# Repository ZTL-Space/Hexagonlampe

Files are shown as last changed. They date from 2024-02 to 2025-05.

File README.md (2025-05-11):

# Hexagonlampe

Die Hexagonlampe wird aus CNC-Gefrästen Holz- und Plexiglasteilen zusammengebaut.

Die Idee stammt von [hier](https://hackaday.com/2019/02/21/hexagonal-lamp-is-a-stylish-application-of-plywood/).

Im Gegensatz zum Original werden hier LED-Stripes montiert, die von einem ESP32 angesteuert werden.

Die Steuerung erfolgt über einen Taster, der betätigt wird, wenn man oben auf die Lampe drückt bzw. über WLAN und MQTT.

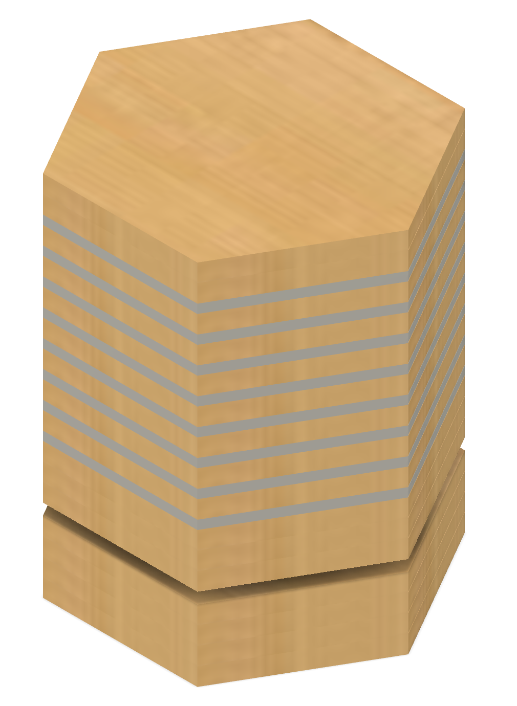
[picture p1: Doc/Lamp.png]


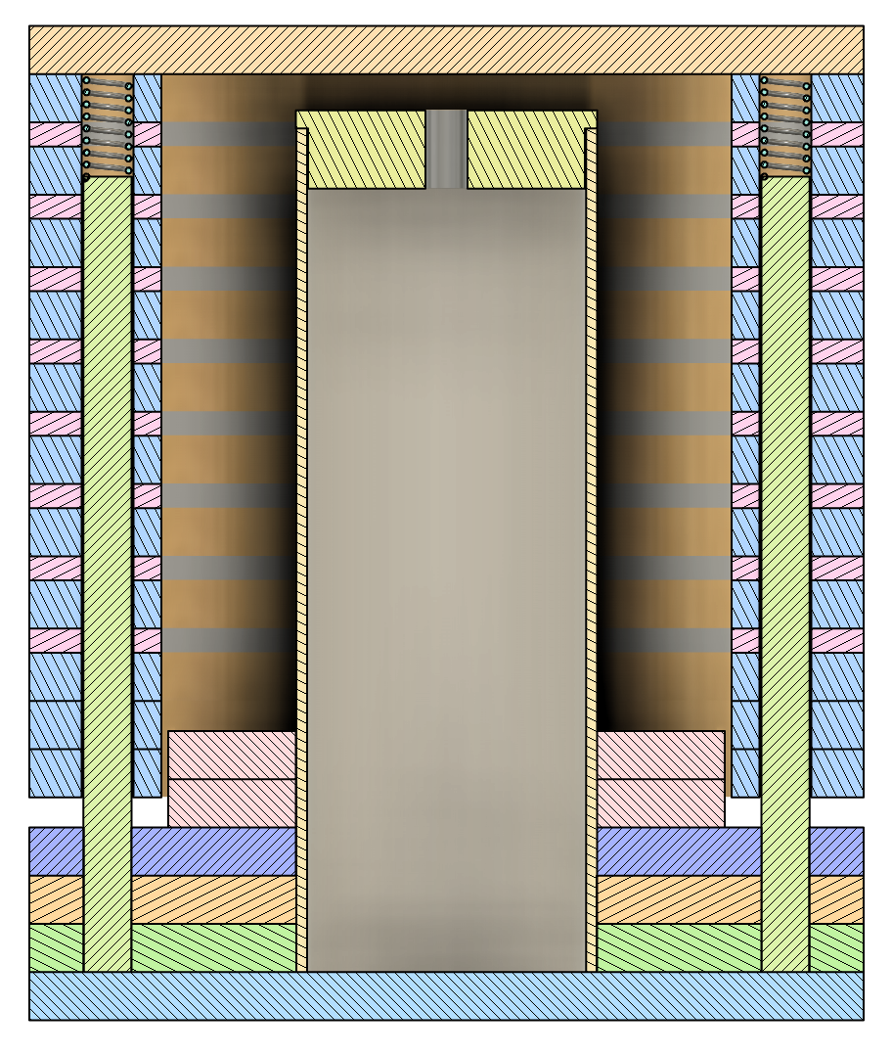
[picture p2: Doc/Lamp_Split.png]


## Bestellliste
- [Hohlstecker](https://www.amazon.de/dp/B0BY161TY7)
- [Federn](https://www.amazon.de/WPERSUVV-3D-Druckfedern-Druckfedern-Lichtlast-Kompression/dp/B07RGW1D2K/)
- [ESP32](https://www.amazon.de/AZDelivery-Bluetooth-Internet-Entwicklungsboard-kompatibel/dp/B08BTYCGVV/)
- [5V-Steckernetzteile](https://www.henri.de/stromversorgung/steckernetzteile/steckernetzteil-5v-dc/33298/5v-steckernetzteil-5v-12w-2-4a-stecker-5-5x2-1mm-eingang-230v-pce-serie.html)
- [Holz](https://www.hornbach.de/p/fixmass-sperrholz-buche-1200x600x8-mm/6617847/)
- [Hobbyglas](https://www.hornbach.de/p/hobbyglas-4x500x1500-mm-glatt-klar/1477889/)
- [Linearführungen](https://www.ebay.de/itm/154359814328)
- [Taster](https://www.amazon.de/VISSQH-Momentane-Druckschalter-Lockless-Armaturenbrett/dp/B08526NQNL/)
- [LED-Stripes](https://de.aliexpress.com/item/32476317187.html)

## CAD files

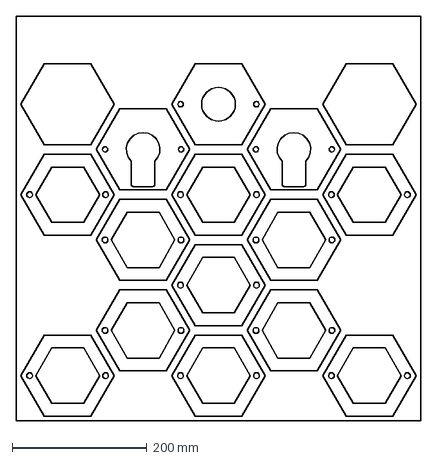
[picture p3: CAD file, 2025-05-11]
3D/DXF/Holz_Kombiniert_600x600.dxf
600.0 x 600.0 mm

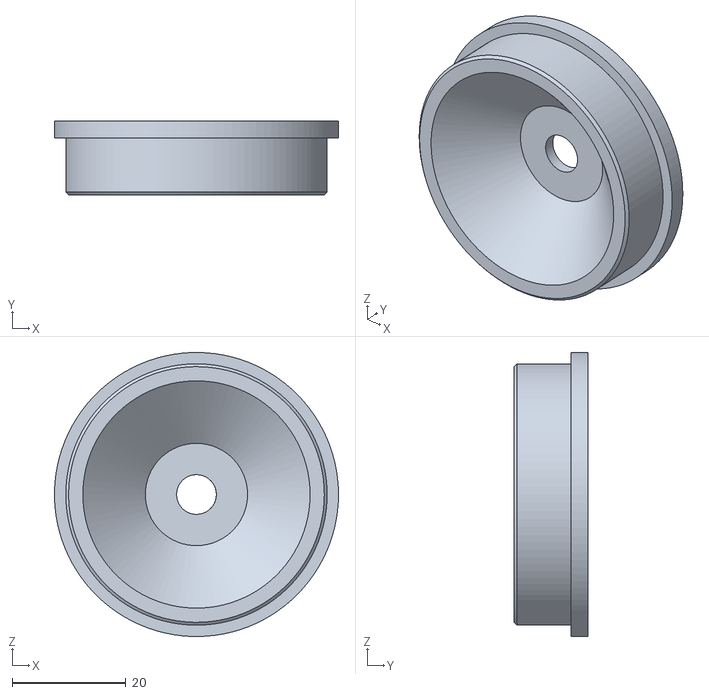
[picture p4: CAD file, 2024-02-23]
3D/STL/Rohrdeckel.stl
50.0 x 13.0 x 50.0

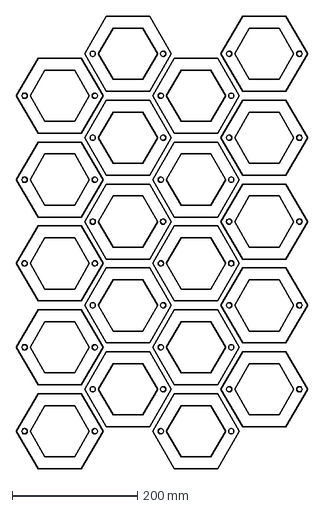
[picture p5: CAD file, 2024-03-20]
3D/DXF/Plexiglas_Kombiniert_750x500.dxf
465.7 x 723.6 mm

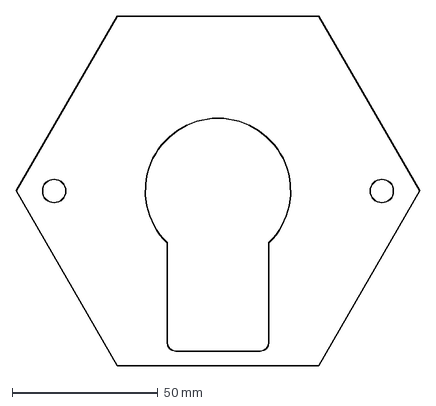
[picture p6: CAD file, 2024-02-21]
3D/DXF/Boden_Layer_2x.dxf
138.6 x 120.0 mm

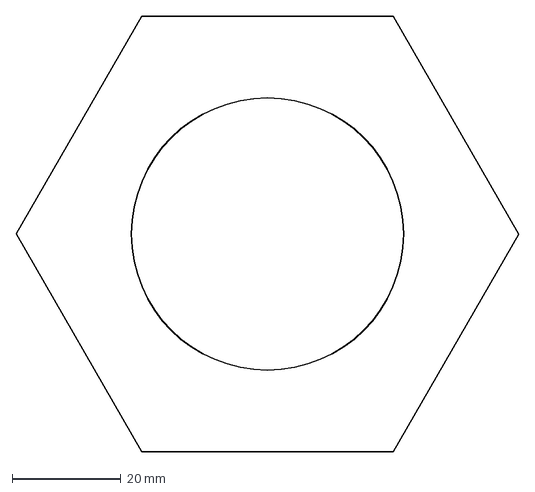
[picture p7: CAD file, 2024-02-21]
3D/DXF/Rohr_Layer_2x.dxf
92.4 x 80.0 mm

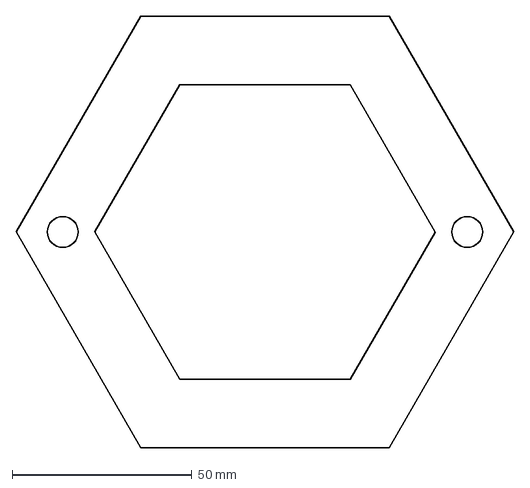
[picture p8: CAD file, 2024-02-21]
3D/DXF/Holz_Layer_11x.dxf
138.6 x 120.0 mm

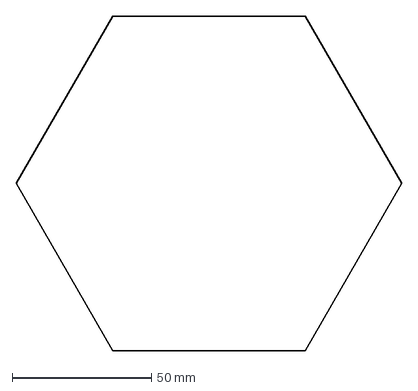
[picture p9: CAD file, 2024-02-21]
3D/DXF/Holz_Abschluss_Layer_1x.dxf
138.6 x 120.0 mm

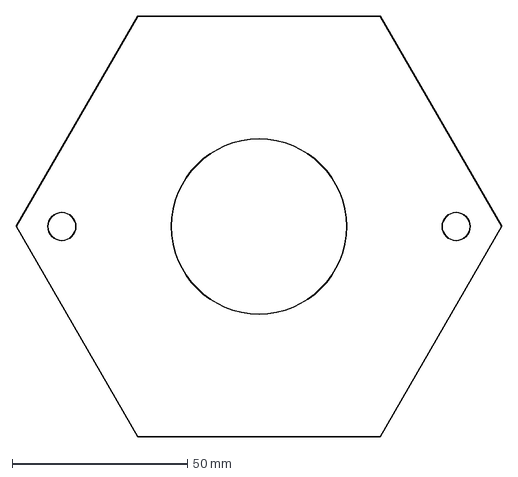
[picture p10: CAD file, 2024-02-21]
3D/DXF/Innen Deckel 1x.dxf
138.6 x 120.0 mm

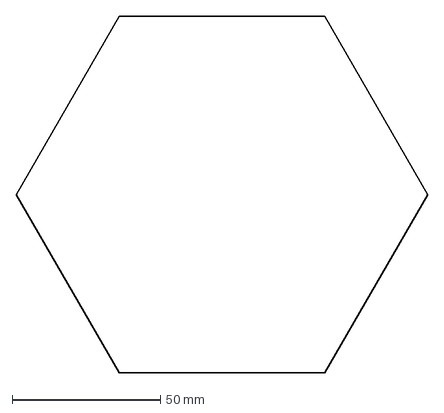
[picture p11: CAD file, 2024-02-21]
3D/DXF/Boden_1x.dxf
138.6 x 120.0 mm

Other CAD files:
3D/Hexagon_Lampe_ZTL.f3d

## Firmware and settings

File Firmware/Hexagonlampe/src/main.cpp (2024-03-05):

#include <Adafruit_NeoPixel.h>
#include <Arduino.h>

#include <PubSubClient.h>
#include <WiFi.h>

#define PIN_WS2812B 16 // The ESP32 pin GPIO16 connected to WS2812B
#define NUM_PIXELS 5   // The number of LEDs (pixels) on WS2812B LED strip
#define PIN_BUTTON 27

Adafruit_NeoPixel ws2812b(NUM_PIXELS, PIN_WS2812B, NEO_GRBW + NEO_KHZ800);

const char *ssid = "";
const char *password = "";
const char *mqtt_server = "";

const char *topic = "ztl";

WiFiClient espClient;
PubSubClient client(espClient);

bool ButtonMessageReceivedFlag = false;
bool IAmTheFirstSender = false;

enum State
{
    OFF,
    PRIMARY_COLOR,
    SECONDARY_COLOR
};

void HandleSignal();
void HandleButton();

void setup_wifi()
{

    delay(10);
    // We start by connecting to a WiFi network
    Serial.println();
    Serial.print("Connecting to ");
    Serial.println(ssid);

    WiFi.mode(WIFI_STA);
    WiFi.begin(ssid, password);

    while (WiFi.status() != WL_CONNECTED)
    {
        delay(500);
        Serial.print(".");
    }

    randomSeed(micros());

    Serial.println("");
    Serial.println("WiFi connected");
    Serial.println("IP address: ");
    Serial.println(WiFi.localIP());
}

void callback(char *topic, byte *payload, unsigned int length)
{
    Serial.print("Message arrived [");
    Serial.print(topic);
    Serial.print("] ");
    for (int i = 0; i < length; i++)
    {
        Serial.print((char)payload[i]);
    }
    Serial.println();

    // Switch on the LED if an 1 was received as first character
    if ((char)payload[0] == '1')
    {
        ButtonMessageReceivedFlag = true;
    }
}

void reconnect()
{
    ws2812b.fill(ws2812b.Color(255, 0, 0, 0));
    ws2812b.show();

    // Loop until we're reconnected
    while (!client.connected())
    {
        Serial.print("Attempting MQTT connection...");
        // Create a random client ID
        String clientId = "ESP8266Client-";
        clientId += String(random(0xffff), HEX);
        // Attempt to connect
        if (client.connect(clientId.c_str()))
        {
            Serial.println("connected");
            client.subscribe(topic);
        }
        else
        {
            Serial.print("failed, rc=");
            Serial.print(client.state());
            Serial.println(" try again in 5 seconds");
            // Wait 5 seconds before retrying
            delay(5000);
        }
    }

    ws2812b.fill(ws2812b.Color(0, 0, 0, 0));
    ws2812b.show();
}

void setup()
{
    pinMode(PIN_BUTTON, INPUT_PULLUP);

    ws2812b.begin();
    ws2812b.fill(ws2812b.Color(0, 0, 255, 0));
    ws2812b.show();

    Serial.begin(115200);
    setup_wifi();
    client.setServer(mqtt_server, 1883);
    client.setCallback(callback);
}

void loop()
{
    if (!client.connected())
    {
        reconnect();
    }
    client.loop();

    HandleSignal();
    HandleButton();
}

void HandleSignal()
{
    static State state = State::OFF;
    static unsigned long timeout = 0xFFFFFFFF;
    unsigned long now = millis();

    switch (state)
    {
    case State::OFF:
        if (ButtonMessageReceivedFlag)
        {
            ws2812b.fill(ws2812b.Color(255, 0, 0, 0));
            ws2812b.show();
            timeout = millis() + 30 * 1000;
            state = State::PRIMARY_COLOR;
        }
        break;
    case State::PRIMARY_COLOR:
        if (ButtonMessageReceivedFlag)
        {
            ws2812b.fill(ws2812b.Color(0, 0, 0, 255));
            ws2812b.show();
            timeout = millis() + 30 * 1000;
            state = State::SECONDARY_COLOR;
        }
        else if (now > timeout)
        {
            state = State::OFF;
            ws2812b.fill(ws2812b.Color(0, 0, 0, 0));
            ws2812b.show();
            IAmTheFirstSender = false;
        }
        break;
    case State::SECONDARY_COLOR:
        if (now > timeout)
        {
            state = State::OFF;
            ws2812b.fill(ws2812b.Color(0, 0, 0, 0));
            ws2812b.show();
            IAmTheFirstSender = false;
        }
        break;
    }

    ButtonMessageReceivedFlag = false;
}

void HandleButton()
{
    if (!digitalRead(PIN_BUTTON) && IAmTheFirstSender == false)
    {
        client.publish(topic, "1");
        IAmTheFirstSender = true;
    }
}

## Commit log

2024-02-21 ADD SVG and Fusion
    [Hexagon_Lampe_ZTL.f3d]
2024-02-21 Create Rohrdeckel.stl
    Add Rohrdeckel
    [Rohrdeckel.stl]
2024-02-21 Create Boden_1x.dxf
    Add DXF
    [Boden_1x.dxf]
2024-02-21 Create Boden_Layer_oben_1x.dxf
    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
    [Boden_Layer_oben_1x.dxf]
2024-02-21 Create Holz_Abschluss_Layer_1x.dxf
    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
    [Holz_Abschluss_Layer_1x.dxf]
2024-02-21 Add DXF
    [Boden_Layer_2x.dxf, Hexagon_Lampe_ZTL.f3d, Holz_Layer_11x.dxf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]
2024-02-23 Update README.md LED-Stripe-Link
2024-02-23 Rohrdeckel geändert
    Rohrdeckel geändert damit der Schalter passt.
    [Hexagon_Lampe_ZTL.f3d, Rohrdeckel.stl]
2024-03-07 Deckel innen 1x hinzugefügt
    [Innen Deckel 1x.dxf]
2024-03-20 add plexi combined files
    [Plexiglas_Kombiniert_750x500.dxf]
2025-05-11 add wood combined files
    [Holz_Kombiniert_600x600.dxf]
